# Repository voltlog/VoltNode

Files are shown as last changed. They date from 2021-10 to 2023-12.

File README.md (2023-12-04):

# VoltNode™
VoltNode™ is a SA818 based UHF/VHF node designed to be compatible with the open source [SVXLink project](https://github.com/sm0svx/svxlink "SVXLink project"). The PCB was designed to fit over the OrangePiZero and the schematic and GPIO choice is based on the original work of the [ROLink community](http://www.439100.ro/ "ROLink community"), with the goal of having this hardware compatible with ready made OS images create by the ROLink community.

More info about this project in [Voltlog #385](https://youtu.be/EprSIw-5l6w).

Checkout assembly.pdf above for a drawing with component position and designators. This should help when you are assembling the PCB.

Someone designed a [3D printable case](https://www.thingiverse.com/thing:6345499) for the VoltNode. 

Known issues in revA: The mic negative input on the orangepizero is left floating which could lead to some input noise being amplified. A fix is indicated in the schematic.

revB: Addressed the issue by addig capacitor to MIC1N.

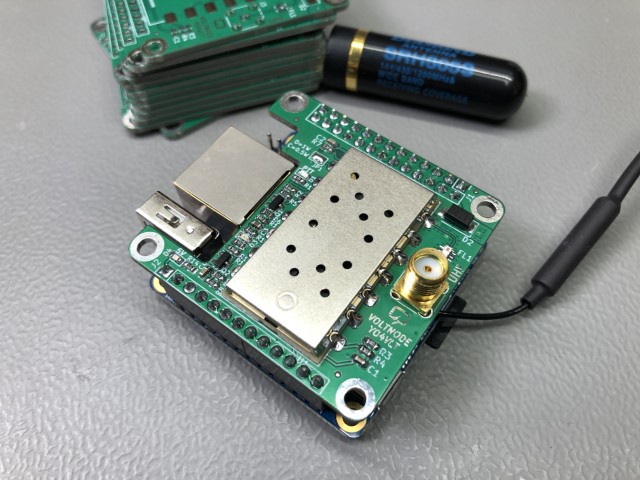
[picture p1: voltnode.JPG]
Image of the assembled PCB


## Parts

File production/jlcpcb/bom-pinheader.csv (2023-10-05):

Designator | Footprint | Quantity | Value | LCSC Part #
J1 | PinHeader_2x13_P2.54mm_Vertical | 1 | Conn_02x13_Odd_Even | C2894974
J2 | PinHeader_1x13_P2.54mm_Vertical | 1 | Conn_01x13 | C2894936
J3 | PinSocket_2x13_P2.54mm_Vertical | 1 | Conn_02x13_Odd_Even | C2897414
J4 | PinSocket_1x13_P2.54mm_Vertical | 1 | Conn_01x13 | C2897376

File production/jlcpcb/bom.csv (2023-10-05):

Designator | Footprint | Quantity | Value | LCSC Part #
C1, C3, C5 | 0603 | 3 | 470nF
C2, C4 | 0603 | 2 | 0,1uF
D1 | 0603 | 1 | LED | C72043
D2 | D_SMA | 1 | 1N4001
D3 | 0603 | 1 | LED | C2286
D4 | 0603 | 1 | LED | C72038
FL1 | 0500LP15A500 | 1 | 0500LP15A500E
J3 | SMA_Amphenol_132134_Vertical | 1 | Conn_Coaxial | C914559
Q1 | SOT-23 | 1 | BC847
Q2 | SOT-23 | 1 | BC857
R1, R13 | 0603 | 2 | 330R
R10, R15, R2, R8 | 0603 | 4 | 2K2
R11, R3 | 0603 | 2 | 1K
R12, R4, R7 | 0603 | 3 | 10K
R14 | 0603 | 1 | 470R
R5, R9 | 0603 | 2 | 47K
R6 | 0603 | 1 | 4K7
U1 | SA818 | 1 | SA818

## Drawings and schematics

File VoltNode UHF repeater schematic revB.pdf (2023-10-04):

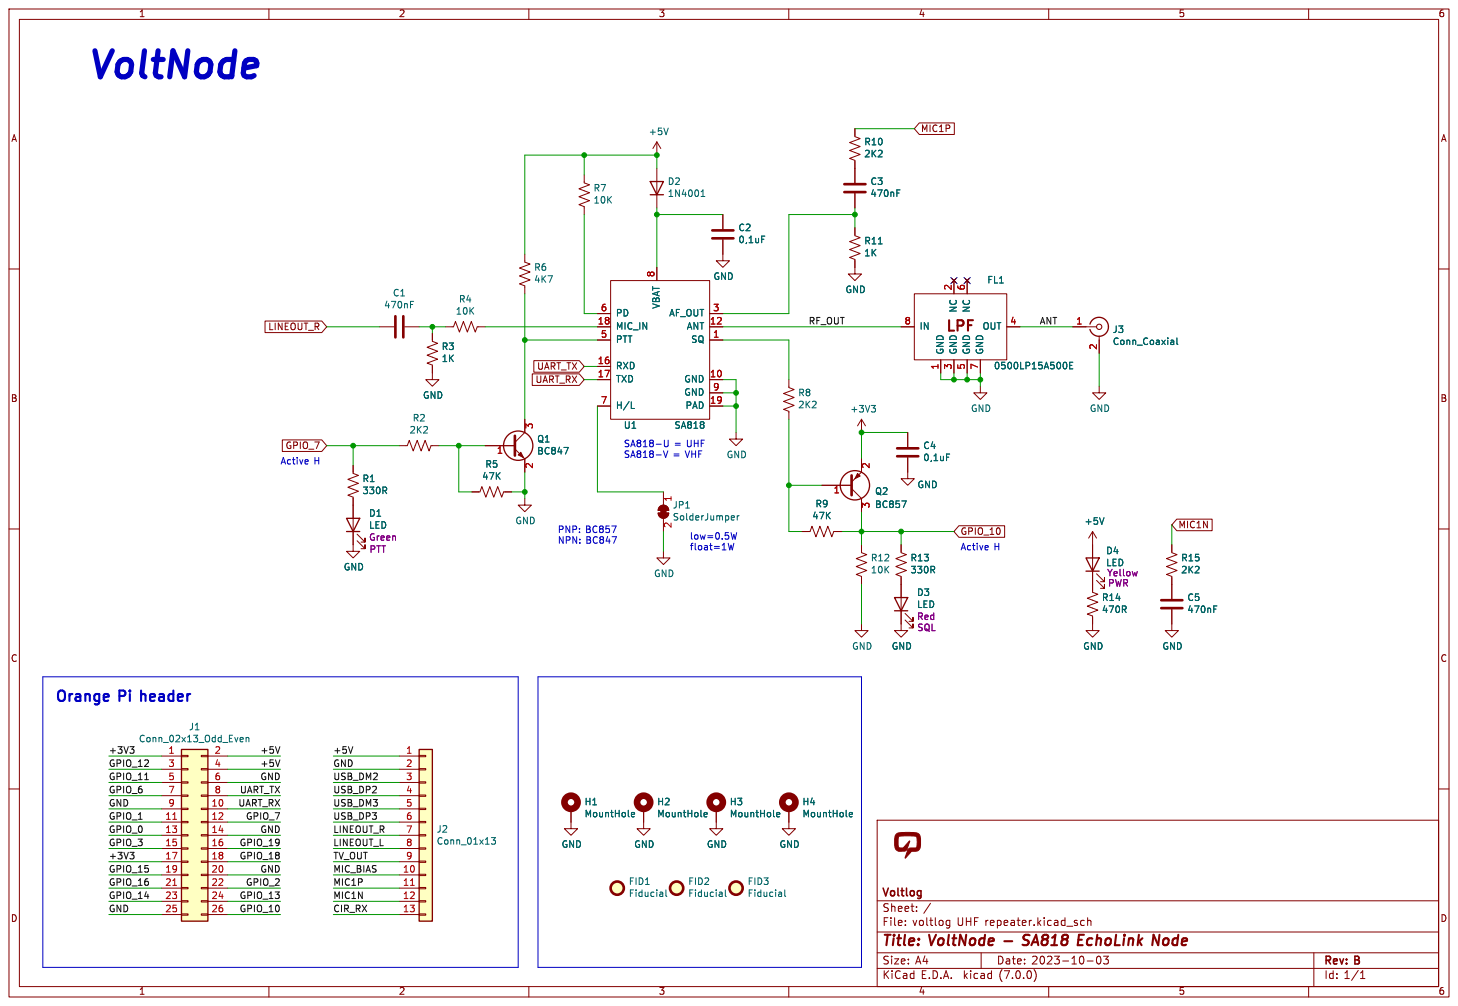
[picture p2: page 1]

File: voltlog UHF repeater.kicad_sch Sheet: / Voltlog

Id: 1/1 Title: VoltNode - SA818 EchoLink Node

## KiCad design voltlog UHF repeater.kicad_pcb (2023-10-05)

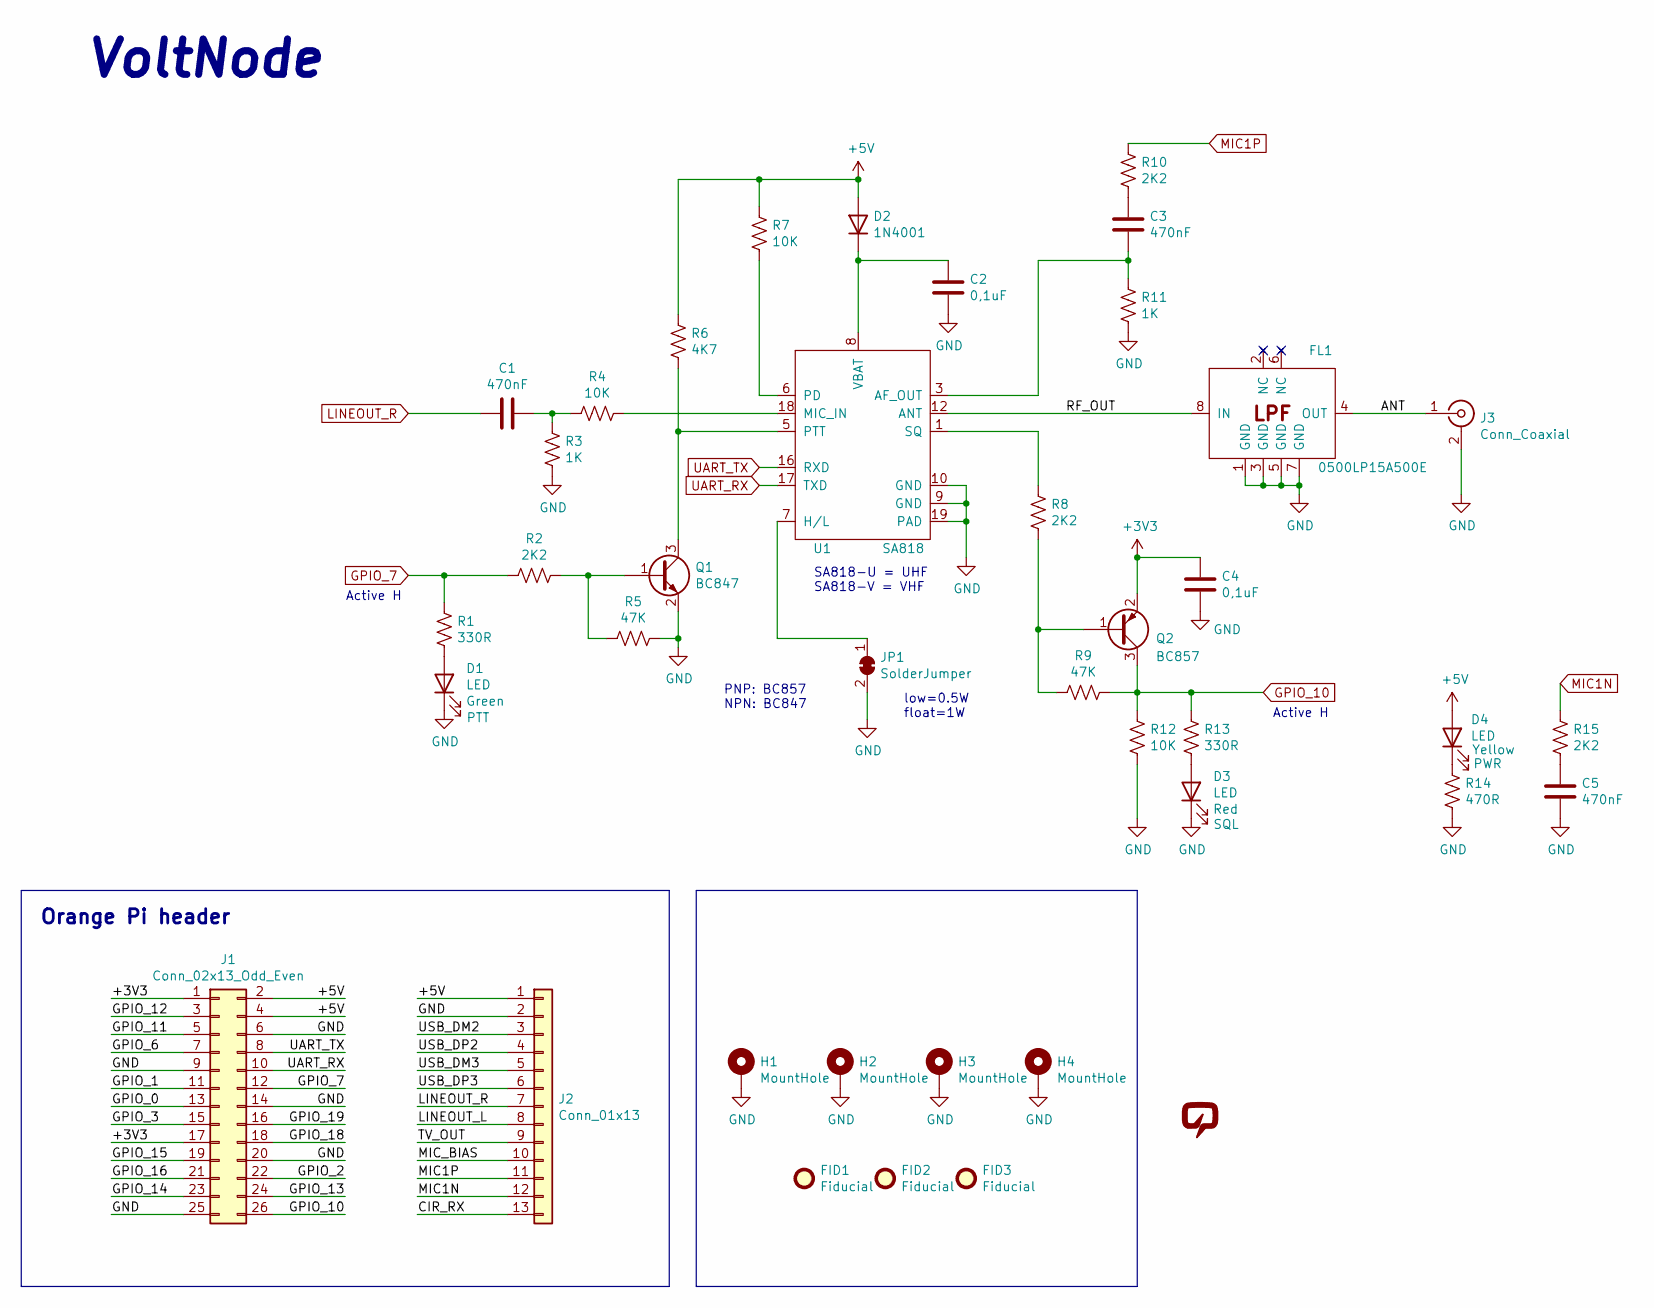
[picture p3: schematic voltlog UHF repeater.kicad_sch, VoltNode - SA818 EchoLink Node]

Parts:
C1, C3, C5: 470nF; C_0603_1608Metric
C2, C4: 0,1uF; C_0603_1608Metric
D1: LED; LED_0603_1608Metric; JLCPCB Part # C72043
D2: 1N4001; D_SMA
D3: LED; LED_0603_1608Metric; JLCPCB Part # C2286
D4: LED; LED_0603_1608Metric; JLCPCB Part # C72038
FID1, FID2, FID3: Fiducial; Fiducial_0.5mm_Mask1mm
FL1: 0500LP15A500E; 0500LP15A500
H1, H2, H3, H4: MountHole; MountingHole_3.2mm_M3_ISO14580_Pad
J1: Conn_02x13_Odd_Even; PinHeader_2x13_P2.54mm_Vertical; JLCPCB Part # C2894974
J2: Conn_01x13; PinHeader_1x13_P2.54mm_Vertical; JLCPCB Part # C2894936
J3: Conn_Coaxial; SMA_Amphenol_132134_Vertical; JLCPCB Part # C914559
JP1: SolderJumper; SolderJumper-2_P1.3mm_Open_TrianglePad1.0x1.5mm
Q1: BC847; SOT-23
Q2: BC857; SOT-23
R1, R13: 330R; R_0603_1608Metric
R2, R8, R10, R15: 2K2; R_0603_1608Metric
R3, R11: 1K; R_0603_1608Metric
R4, R7, R12: 10K; R_0603_1608Metric
R5, R9: 47K; R_0603_1608Metric
R6: 4K7; R_0603_1608Metric
R14: 470R; R_0603_1608Metric
U1: SA818
V1: VOLTLOG_LOGO; voltlog_mask_3mm

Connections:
+3V3: C4.1, J1.1, J1.17, Q2.2 (E)
+5V: D2.2 (A), D4.2 (A), J1.2, J1.4, J2.1, R6.1, R7.1
/ANT: FL1.4 (OUT), J3.1 (In)
/CIR_RX: J2.13
/GPIO_0: J1.13
/GPIO_1: J1.11
/GPIO_2: J1.22
/GPIO_3: J1.15
/GPIO_6: J1.7
/GPIO_11: J1.5
/GPIO_12: J1.3
/GPIO_13: J1.24
/GPIO_14: J1.23
/GPIO_15: J1.19
/GPIO_16: J1.21
/GPIO_18: J1.18
/GPIO_19: J1.16
/LINEOUT_L: J2.8
/MIC_BIAS: J2.10
/RF_OUT: FL1.8 (IN), U1.12 (ANT)
/TV_OUT: J2.9
/USB_DM2: J2.3
/USB_DM3: J2.5
/USB_DP2: J2.4
/USB_DP3: J2.6
GND: C2.2, C4.2, C5.2, D1.1 (K), D3.1 (K), FL1.1 (GND), FL1.3 (GND), FL1.5 (GND), FL1.7 (GND), H1.1, H2.1, H3.1, H4.1, J1.6, J1.9, J1.14, J1.20, J1.25, J2.2, J3.2 (Ext), JP1.2 (B), Q1.2 (E), R3.2, R5.1, R11.2, R12.2, R14.2, U1.9 (GND), U1.10 (GND), U1.19 (PAD)
GPIO_7: J1.12, R1.1, R2.2
GPIO_10: J1.26, Q2.3 (C), R9.2, R12.1, R13.1
LINEOUT_R: C1.2, J2.7
MIC1N: J2.12, R15.1
MIC1P: J2.11, R10.1
unnamed: C1.1, R3.1, R4.2
unnamed: C3.1, R10.2
unnamed: C5.1, R15.2
unnamed: D1.2 (A), R1.2
unnamed: C2.1, D2.1 (K), U1.8 (VBAT)
unnamed: D3.2 (A), R13.2
unnamed: D4.1 (K), R14.1
unnamed: JP1.1 (A), U1.7 (H/L)
unnamed: Q1.1 (B), R2.1, R5.2
unnamed: Q1.3 (C), R6.2, U1.5 (PTT)
unnamed: Q2.1 (B), R8.2, R9.1
unnamed: C3.2, R11.1, U1.3 (AF_OUT)
unnamed: R4.1, U1.18 (MIC_IN)
unnamed: R7.2, U1.6 (PD)
unnamed: R8.1, U1.1 (SQ)
UART_RX: J1.10, U1.17 (TXD)
UART_TX: J1.8, U1.16 (RXD)

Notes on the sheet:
Orange Pi header
SA818-U = UHF SA818-V = VHF
Active H
low=0.5W float=1W
VoltNode
PNP: BC857 NPN: BC847

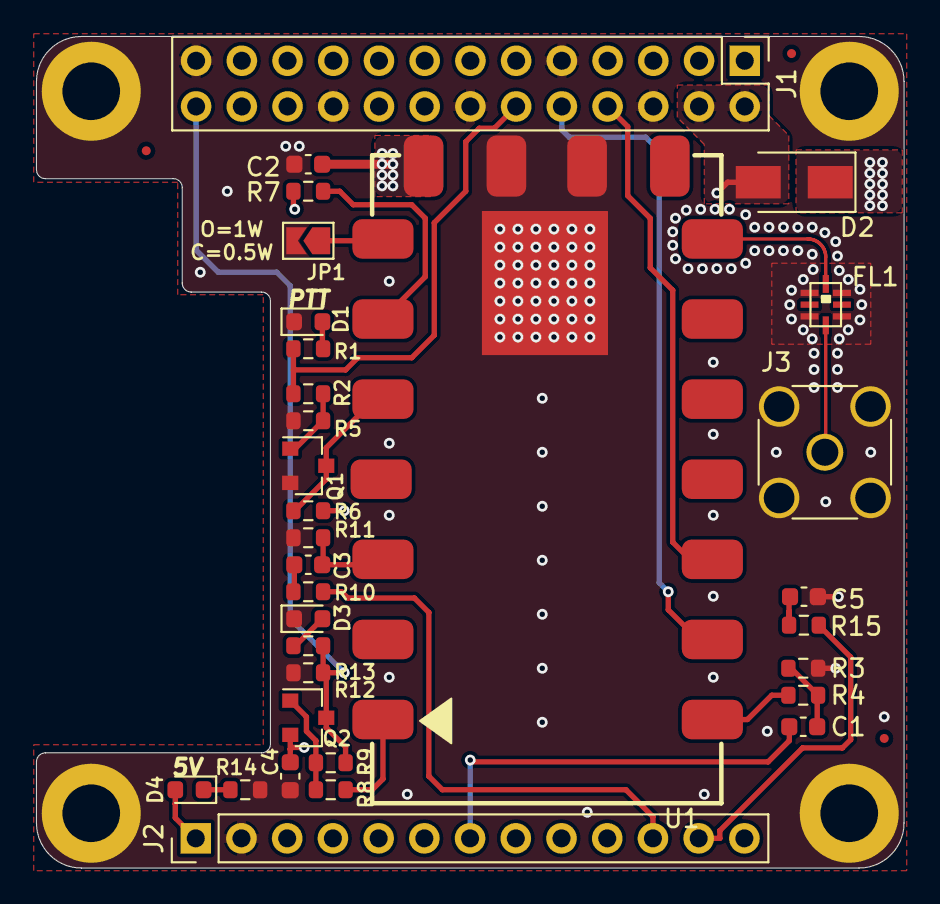
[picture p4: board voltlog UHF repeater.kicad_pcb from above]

Board: 4 copper layers, 48.2 x 46.2 mm, 39 parts (0 on the bottom side), 27 nets.

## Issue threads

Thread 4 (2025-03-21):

Raspberry pi Zero

uguraltinsoy, 2025-03-21:
Is it possible to use this project for Raspberry pi Zero?

voltlog, 2025-03-21:
The README file specifies clearly "The PCB was designed to fit over the OrangePiZero".

Closed 2025-03-21.

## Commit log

2023-10-03 Added pulldown for MIC1N. Added part no for JLCPCB and production files for JLCPCB.
    [bom.csv, designators.csv, positions.csv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]
2023-10-04 Fixed errors caused by orangepi outline present in Margin layer
    [voltlog UHF repeater-B_Cu.gbr, voltlog UHF repeater-B_Mask.gbr, voltlog UHF repeater-B_Paste.gbr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]
2023-10-04 Cleanup in bom and position file.
    [bom-pinheader.csv, bom.csv, positions.csv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]
2023-12-04 Added link to 3D printable enclosure
